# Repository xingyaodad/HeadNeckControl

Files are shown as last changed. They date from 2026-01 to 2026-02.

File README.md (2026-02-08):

# 🤖 HeadNeckControl

<div align="center">

## 🎯 基于RBF的仿生颈部舵机控制系统

### 🦾 通过肌腱实现仿生头部的实时控制和动画播放

</div>

---

## 📹 效果展示

### 👻 仿生脖子运行演示

<div align="center">

 <!-- 替换为你的实际 GIF 文件 -->
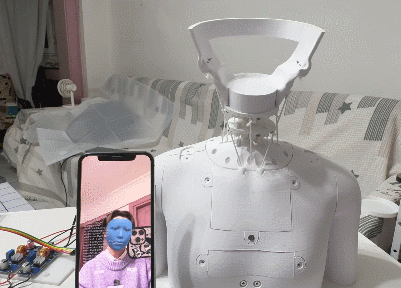
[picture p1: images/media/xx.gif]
仿生脖子运行演示


✨ *仿生脖子实时追踪演示* ✨

</div>

---

## 📖 项目简介

HeadNeckControl 是一个完整的仿生颈部控制系统，通过树莓派和 PCA9685 驱动舵机拉动肌腱来模拟肌肉的方式控制仿生头部的运动。系统支持多种控制方式：手机 ARKit 面部追踪、动画文件播放、Windows 端手动控制和测试模式，可以精确控制头部的俯仰、偏航和滚动三个自由度。

## ✨ 功能特点

- 📱 **ARKit 实时追踪**：通过 iOS 设备使用 ARKit 捕捉面部姿态，通过 UDP 直接发送到树莓派进行实时控制
- 🎮 **Unity iOS 应用**：提供完整的 Unity 项目，用于生成 ARKit 面部追踪 iOS 应用，支持自定义和扩展
- 🎬 **动画播放**：支持播放预设的头部动作序列，动画文件存储在树莓派本地
- 🖱️ **Windows 手动控制**：提供图形界面，可通过滑块直接控制舵机角度
- 🔧 **测试模式**：用于调试和校准舵机的测试模式
- 🎨 **平滑过渡**：使用 RBF（径向基函数）插值算法，实现流畅的动作过渡
- 🔄 **多输入源**：支持多种输入源的灵活切换

## 🏗️ 系统架构

```
┌─────────────────┐     UDP      ┌──────────────────┐
│  Windows App    │ ───────────> │  Raspberry Pi    │
│  (C# .NET 8)    │              │   (Python 3.11)  │
│                 │              │                  │
│  - TrackBar     │              │  - BaseInput     │
│  - 手动控制      │              │  - HeadMapper    │
└─────────────────┘              │ - ServoController│
                                 └────────┬─────────┘
                                          │
                            UDP           │ I2C
┌─────────────────┐                       │
│   iOS Device    │ ──────────────────────┤
│   (ARKit)       │                       ▼
└─────────────────┘              ┌──────────────┐
                                 │   PCA9685    │
                                 │ (PWM Driver) │
                                 └──────┬───────┘
                                        │
                                       舵机
                                        ▼
                                 ┌──────────────┐
                                 │  仿生头部     │
                                 └──────────────┘
```

**📡 数据流向说明**：
- 💻 **Windows 端**：通过滑块手动控制舵机角度，通过 UDP 发送舵机角度数据到树莓派
- 🍎 **iOS ARKit 端**：直接通过 UDP 发送 ARKit 捕捉的面部姿态数据到树莓派
- 🎞️ **动画播放**：动画文件（`.anim`）存储在树莓派本地，由树莓派读取并播放
- 🥧 **树莓派**：作为控制中心，接收所有输入源数据，经过 HeadMapper 映射后控制舵机

## 🛒 硬件清单

### 📦 必备硬件

- 🥧 **树莓派**：3B+ 或更高版本
- 💻 **windows电脑**：随意，与树莓派需连统一局域网
- 🔌 **PCA9685 PWM 驱动板**：一块
- ⚙️ **舵机**：MG996R 或类似的金属齿轮舵机 （8个），每个需要十字舵臂，提前设置到90度
- 🔋 **电源**：12V 100W电源 + 2-4个5V5A降压模块（可根据实际情况调整）
- 🔗 **杜邦线、导线**：若干，连接电源、树莓派、PCA9685 和舵机
- 🧵 **dyneema绳**：直径1.5mm 5米，使用前需要做预拉伸（找个重物吊个一两天）裁成12条35cm长的线段
- 🔬 **特氟龙硬管**：内径2mm * 外径3mm 2米，根据image文件夹里的图片截成相应长度的段
- 💎 **陶瓷眼**：小外径3.9 * 孔2.3 * 总高6 （25个）
- ⭕ **小轴承**：9 * 14 * 2.5 （8个）
- 🫧 **TPU胶圈**：直径8mm * 宽2mm （8个），可以用差不多的橡皮筋
- 💧 **胶水**：502或其他快干胶
- 🔩 **螺丝**：平头自攻M3 * 8 （50个），平头M3 * 5 (8个),平头自攻M2 * 10 （32个），平头自攻M2 * 8 （12个），M2 * 10 + 螺母 （8组）（螺丝建议多备些，很容易丢😅）

### 🛠️ 可选硬件

- 🧩 **面包板（可选）**：用于电路连接
- 🧴 **锁边液（可选）**：用于把毛躁的线头弄顺，可以更好的穿孔，也可以用普通的办公胶水代替
- 🪄 **润滑脂（可选）**：关节交接处的润滑，最好有

### 🔧 希望你可以有的一些工具

- ✂️ **螺丝刀、钳子**：如果没有的话就放弃这个项目吧👋
- 🖨️ **FDM 3D打印机**：最大打印尺寸最好超过200 * 200 * 200，没有的话找个代打吧~
- 💪 **电磨**：用于清理打磨模型粗糙的细节，实在没有用砂纸也不是不行

### 🌟 最后希望你可以有

- 🏆 **很强的动手能力**：这个项目所有东西都需要你自己亲自组装😅
- 💖 **很强的耐心**：这套脖子比例大小是按照真实5-6岁孩子尺寸设计的，很多部件非常小且难安装，所以如果你已经开始了，那么一定要耐心一点❤

## 🚀 快速开始

### 🧩 模型组装以及控制
- **请移步B站观看视频**：[闺女脖子开源啦！！](https://www.bilibili.com/video/BV1u9FxzGEDt)

### 🥧 树莓派环境配置

#### 1️⃣ 系统要求
- **操作系统**：Raspberry Pi OS
- **Python 版本**：Python 3.10 或更高（本系统使用 Python 3.11）
- **内存**：至少 2GB RAM（推荐 4GB）

#### 2️⃣ 克隆项目（建议在pc上克隆好，不要在树莓派上克隆，把RaspberryPi文件夹拷贝到树莓派上）

```bash
cd ~
git clone https://github.com/yourusername/HeadNeckControl.git
cd HeadNeckControl/RaspberryPi
```

#### 3️⃣ 安装 Python 依赖

```bash
# 更新系统
sudo apt update
sudo apt upgrade -y

# 安装系统依赖
sudo apt install -y python3-pip python3-dev

# 安装 Python 包
pip3 install -r requirements.txt
```

#### 4️⃣ 启用 I2C 接口

```bash
# 方法 1：使用 raspi-config
sudo raspi-config
# 选择 Interface Options -> I2C -> Enable

# 方法 2：命令行
sudo apt install -y i2c-tools
sudo raspi-config nonint do_i2c 0

# 重启树莓派
sudo reboot
```

#### 5️⃣ 验证 I2C 连接

重启后，检查 PCA9685 是否被识别：🔍

```bash
# 列出所有 I2C 设备
i2cdetect -y 1

# 应该看到类似输出（0x40 是 PCA9685 默认地址）：
#      0  1  2  3  4  5  6  7  8  9  a  b  c  d  e  f
# 00:          -- -- -- -- -- -- -- -- -- -- -- -- --
# 10: -- -- -- -- -- -- -- -- -- -- -- -- -- -- -- --
# 20: -- -- -- -- -- -- -- -- -- -- -- -- -- -- -- --
# 30: -- -- -- -- -- -- -- -- -- -- -- -- -- -- -- --
# 40: 40 -- -- -- -- -- -- -- -- -- -- -- -- -- --
# ...
```

如果看到 `40`，说明 PCA9685 已正确连接。

#### 6️⃣ 配置 config.py

编辑 `RaspberryPi/config.py` 文件，根据你的硬件和网络环境修改以下配置：

```python
class Config():
    DEBUG = True              # 调试模式：True=不操作硬件，仅打印数值；False=实际控制舵机
    ip = ''                   # 树莓派 IP 地址（留空自动检测，或手动填写如 '192.168.1.100'）
    port = 9003               # UDP 监听端口（接收 ARKit/Windows 数据）
    servo_count = 8           # 所有舵机数量
    test_servo_count = 8      # 测试模式下舵机数量
    pca9685_address = [0x40]  # PCA9685 驱动板 I2C 地址（可支持多个板）
    pca_frequency = 50        # PWM 频率（Hz），舵机通常为 50
    is_anim = False           # 是否加载动画文件，不用改，根据选项会自动改
    anim_file = 'anim_data/neck.anim'           # 动画文件路径
    neck_config_file = 'controller/neck_matrix_config.json'  # 舵机角度映射配置文件，从widows输出的矩阵文件
```

**⚙️ 配置说明**：
- **首次运行**建议保持 `DEBUG = True`，验证数据接收和映射逻辑正常后再改为 `False`
- `ip` 留空时会自动检测树莓派的 IP 地址；如果网络环境复杂，可手动指定
- `port` 需要与 Windows 端和 iOS 端的发送端口一致
- 如需添加更多 PCA9685 板，在 `pca9685_address` 列表中添加地址（如 `[0x40, 0x41]`）
- `neck_config_file` 中的配置由 Windows 端的工具生成

## 📁 项目结构

```
HeadNeckControl/
 ├── RaspberryPi/              # 树莓派端代码（Python）
 │   ├── main.py             # 主程序入口
 │   ├── config.py           # 配置文件
 │   ├── controller/         # 控制器模块
 │   │   ├── servo_controller.py   # 舵机控制器
 │   │   └── head_mapper.py       # 头部姿态映射器
 │   ├── input/              # 输入源模块
 │   │   ├── base_input.py        # 输入源基类
 │   │   ├── input_arkit.py       # ARKit 输入源
 │   │   ├── input_anim.py        # 动画文件输入源
 │   │   ├── input_ai.py          # AI 输入源
 │   │   └── input_test.py       # 测试输入源
 │   ├── utils/              # 工具模块
 │   │   └── filetools.py        # 文件处理工具
 │   ├── anim_data/          # 动画文件目录
 │   └── requirements.txt    # Python 依赖
 │
 ├── Windows/                # Windows 端代码（C#）
 │   └── NeckControlOutput/
 │       ├── Form1.cs            # 主窗体
 │       ├── Form1.Designer.cs   # 窗体设计器（自动生成）
 │       ├── Models.cs           # 数据模型
 │       ├── RBFHelper.cs        # RBF 插值助手
 │       ├── WeightMatrixHelper.cs # 权重矩阵计算
 │       ├── Program.cs          # 程序入口
 │       └── NeckControlOutput.csproj # 项目文件
 │
 ├── UnityArkit/              # Unity iOS ARKit 应用
 │   ├── Assets/             # Unity 资源和脚本
 │   │   ├── Scenes/          # 场景文件
 │   │   ├── Scripts/         # C# 脚本
 │   │   └── Samples/         # AR Foundation 示例
 │   ├── Packages/           # Unity 包配置
 │   ├── ProjectSettings/     # 项目设置
 │   └── UnityArkit.sln     # 解决方案文件
 │
 ├── 3D-Models/              # 3D 打印模型文件
 │   ├── OBJ/                 # Wavefront OBJ 格式模型
 │   ├── 3MF/                 # Bambu Studio 切片格式模型
 │   └── README.md            # 3D 打印说明
 │
 ├── AGENTS.md               # 开发者指南
 ├── CHECKLIST.md            # 项目检查清单
 ├── CONTRIBUTING.md         # 贡献指南
 ├── LICENSE                # MIT 许可证
 ├── PACKAGING.md            # 打包发布指南
 ├── README.md              # 本文件
 └── .gitignore            # Git 忽略规则
 ```

## 🤝 贡献

欢迎贡献代码、报告问题或提出改进建议！请阅读 [CONTRIBUTING.md](CONTRIBUTING.md) 了解详情。

## 📜 许可证

本项目采用 MIT 许可证 - 详见 [LICENSE](LICENSE) 文件。

## 🙏 致谢

- Adafruit 的 [CircuitPython](https://circuitpython.org/) 库

## 📺 欢迎围观我的B站

- 📺 B站 [星瑶爸爸呀](https://space.bilibili.com/26313918)

---

<div align="center">

**Made with ❤️ by 🌟 Robotics Enthusiasts** 🤖✨

</div>

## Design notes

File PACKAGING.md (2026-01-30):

# 打包发布指南

本文档说明如何打包和发布 HeadNeckControl 项目。

## Windows 端打包

### 1. 编译 Release 版本

```bash
cd Windows/NeckControlOutput
dotnet build --configuration Release
```

编译后的文件位于：`bin/Release/net8.0-windows/`

### 2. 复制配置文件

Release 编译不会自动包含配置文件，需要手动复制：

```bash
cp neck_config.example.json bin/Release/net8.0-windows/neck_config.json
```

### 3. 打包为 ZIP

将以下文件打包为 ZIP：
- `NeckControlOutput.exe`
- `NeckControlOutput.dll`
- `NeckControlOutput.deps.json`
- `NeckControlOutput.runtimeconfig.json`
- `NumSharp.dll`
- `Numpy.dll`
- `Python.Runtime.dll`
- `Python.Included.dll`
- `Python.Deployment.dll`
- `neck_config.json`

```bash
cd bin/Release/net8.0-windows
zip -r HeadNeckControl-Windows.zip *.dll *.json *.exe
```

### 4. 用户使用

用户下载 ZIP 后：
1. 解压到任意目录
2. 双击 `NeckControlOutput.exe` 运行
3. 首次运行会自动加载或创建配置文件

## 树莓派端打包

### 1. 确保配置文件完整

```bash
cd RaspberryPi
ls -la controller/neck_matrix_config.json
```

### 2. 打包为 ZIP

```bash
cd RaspberryPi
zip -r HeadNeckControl-RaspberryPi.zip \
  *.py \
  config.py \
  controller/ \
  input/ \
  utils/ \
  requirements.txt
```

### 3. 用户部署

用户下载 ZIP 后：
```bash
# 解压
unzip HeadNeckControl-RaspberryPi.zip -d ~/HeadNeckControl
cd ~/HeadNeckControl

# 安装依赖
pip3 install -r requirements.txt

# 运行
python3 main.py
```

## GitHub Release

### 1. 创建 Tag

```bash
git tag -a v1.0.0 -m "Release v1.0.0"
git push origin v1.0.0
```

### 2. 创建 Release

在 GitHub 上：
1. 进入 "Releases" 页面
2. 点击 "Draft a new release"
3. 选择 Tag: v1.0.0
4. 填写 Release Notes
5. 上传打包的 ZIP 文件：
   - `HeadNeckControl-Windows.zip`
   - `HeadNeckControl-RaspberryPi.zip`
6. 点击 "Publish release"

### 3. Release Notes 模板

```markdown
## HeadNeckControl v1.0.0

### 下载

- [Windows 版本](HeadNeckControl-Windows.zip) - 适用于 Windows 10/11
- [树莓派版本](HeadNeckControl-RaspberryPi.zip) - 适用于 Raspberry Pi OS

### 新功能
- 支持 ARKit 实时面部追踪
- 支持动画文件播放
- Windows 端图形界面手动控制
- RBF 插值平滑过渡

### 系统要求

**Windows**：
- Windows 10/11
- .NET 8.0 Runtime（包含在 ZIP 中）

**树莓派**：
- Raspberry Pi 3B+ 或更高
- Raspberry Pi OS Bullseye/Bookworm
- Python 3.10+

### 快速开始

详细说明请参考 [README.md](../../README.md)

### 已知问题
- 无

### 更新日志
- 初始版本发布
```

## 注意事项

1. **配置文件**：确保示例配置文件包含在发行版中
2. **依赖库**：Windows 端需要将 NuGet 包的 DLL 包含在 ZIP 中
3. **版本号**：更新 NeckControlOutput.csproj 中的版本号
4. **文档**：确保 README 和 AGENTS.md 已更新
5. **测试**：在发布前在干净环境中测试 ZIP 文件

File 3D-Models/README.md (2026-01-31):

# 3D 打印模型文件

本目录包含 HeadNeckControl 仿生颈部控制系统的 3D 打印模型文件。

## 目录结构

```
3D-Models/
├── OBJ/          # Wavefront OBJ 格式模型
├── 3MF/          # Bambu Studio 切片格式文件
└── README.md      # 本文件
```

## 打印建议

### 所有主体
- **材料**：PLA 或 PETG（推荐 PETG）
- **打印参数**：参考3mf文件里的配置

### 颈部连接件
- **材料**：PA（尼龙）
- **打印参数**：参考3mf文件里的配置
- **打磨**：拆完支撑后最好把接触面打磨一下

## 注意事项

**因为制作模型单位问题，如果自己把模型导入切片软件需要放大十倍！！！放大十倍！！！**

## 许可证

3D 模型文件遵循项目的 MIT 许可证。

<div align="center">

**Happy 3D Printing! 🖨️**

</div>

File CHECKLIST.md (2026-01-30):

# 项目检查清单

## 下载后可运行性检查

### 树莓派端

- [x] **.gitignore 配置正确**
  - ✅ `RaspberryPi/controller/neck_matrix_config.json` 已被包含（不会忽略）
  - ✅ 示例文件 `neck_matrix_config.example.json` 已创建
  - ✅ 用户可运行的配置文件存在

- [x] **必需文件已提交**
  - ✅ 所有 Python 源码文件
  - ✅ `requirements.txt` 包含所有依赖
  - ✅ `config.py` 配置文件
  - ✅ `neck_matrix_config.json` 默认配置

- [x] **用户使用流程**
  ```bash
  # 1. 克隆项目
  git clone https://github.com/yourusername/HeadNeckControl.git
  cd HeadNeckControl/RaspberryPi

  # 2. 安装依赖
  pip3 install -r requirements.txt

  # 3. 运行程序
  python3 main.py
  ```

### Windows 端

- [x] **.gitignore 配置正确**
  - ✅ 编译产物（bin/、obj/）已忽略
  - ✅ 用户配置文件 `Windows/NeckControlOutput/*/neck_config.json` 已忽略
  - ✅ 示例文件 `neck_config.example.json` 已创建

- [x] **必需文件已提交**
  - ✅ 所有 C# 源码文件
  - ✅ `NeckControlOutput.csproj` 项目文件
  - ✅ `neck_config.example.json` 示例配置

- [x] **用户使用流程**
  ```bash
  # 1. 克隆项目
  git clone https://github.com/yourusername/HeadNeckControl.git
  cd HeadNeckControl/Windows

  # 2. 编译项目
  dotnet build

  # 3. 运行程序
  cd NeckControlOutput/bin/Debug/net8.0-windows
  ./NeckControlOutput.exe
  ```

## EXE 生成检查

### Debug 模式
- [x] `dotnet build` 成功
- [x] 生成 `NeckControlOutput.exe` 在 `bin/Debug/net8.0-windows/`
- [x] 所有依赖 DLL 已生成
- [x] `neck_config.json` 自动生成或可从示例复制

### Release 模式
- [x] `dotnet build --configuration Release` 成功
- [x] 生成 `NeckControlOutput.exe` 在 `bin/Release/net8.0-windows/`
- [x] 所有依赖 DLL 已生成
- [x] 可打包为独立 ZIP 分发

## 配置文件检查

### 树莓派端
- [x] `neck_matrix_config.json` 存在且格式正确
- [x] `neck_matrix_config.example.json` 作为参考
- [x] 包含 RBF 矩阵和舵机范围配置

### Windows 端
- [x] `neck_config.example.json` 存在且格式正确
- [x] 运行时自动创建 `neck_config.json`
- [x] 包含 IP、端口、舵机标签配置

## 文档完整性

- [x] **README.md**
  - ✅ 项目简介和功能特点
  - ✅ 系统架构图
  - ✅ 硬件清单
  - ✅ 详细的安装步骤（删除了虚拟环境）
  - ✅ 配置文件说明
  - ✅ 常见问题 FAQ
  - ✅ 调试技巧

- [x] **AGENTS.md**
  - ✅ 构建和测试命令
  - ✅ 代码风格指南（Python 和 C#）
  - ✅ 架构设计模式
  - ✅ 常见问题
  - ✅ 纯中文

- [x] **CONTRIBUTING.md**
  - ✅ 贡献指南
  - ✅ Issue 和 PR 流程
  - ✅ 纯中文

- [x] **PACKAGING.md**（新增）
  - ✅ Windows 端打包指南
  - ✅ 树莓派端打包指南
  - ✅ GitHub Release 流程
  - ✅ Release Notes 模板

- [x] **.github/PULL_REQUEST_TEMPLATE.md**
  - ✅ PR 模板

- [x] **LICENSE**
  - ✅ MIT 许可证

## 网络配置检查

- [x] **树莓派**
  - ✅ UDP 端口 9003
  - ✅ IP 地址自动获取或手动配置

- [x] **Windows**
  - ✅ UDP 发送端口 5001
  - ✅ 默认目标地址 192.168.3.11:9003

## 已知问题

### 当前存在的问题
⚠️ `head_mapper.py` 第 21 行没有错误处理
   - 如果配置文件缺失会直接崩溃
   - 建议：添加 try-except 处理文件不存在的情况

### .gitignore 配置说明
✅ 已修复以下问题：
1. 之前：`*config.json` 会忽略所有配置文件
2. 现在：明确指定要保留的配置文件路径

### Windows 端配置文件
✅ 已处理：
1. 示例文件 `neck_config.example.json` 已创建
2. 用户运行时会自动创建 `neck_config.json`
3. Release 打包时需要手动复制配置文件

## 下一步建议

1. **改进错误处理**
   - 在 `head_mapper.py` 中添加配置文件缺失的处理
   - 在 Windows 端添加配置文件损坏的处理

2. **添加安装脚本**
   - 树莓派端：`install.sh` 自动安装依赖和配置
   - Windows 端：安装程序或批处理脚本

3. **添加单元测试**
   - Python 端：pytest 测试
   - Windows 端：xUnit 测试

4. **文档国际化**
   - 考虑添加英文版本 README（根据需要）

## 总结

✅ **项目已完全准备好开源**

用户下载后可以：
1. **树莓派端**：直接运行 `python3 main.py`
2. **Windows 端**：编译后运行 `dotnet run` 或生成的 exe
3. **配置文件**：有默认配置，可直接使用

所有必要的文件都已包含，.gitignore 配置正确，文档完整。

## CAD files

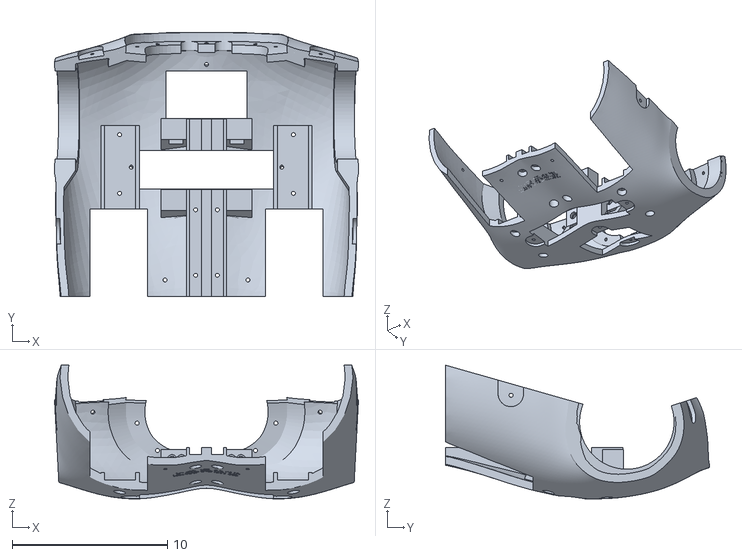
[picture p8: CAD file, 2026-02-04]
3D-Models/body2.obj
19.6 x 17.0 x 8.63

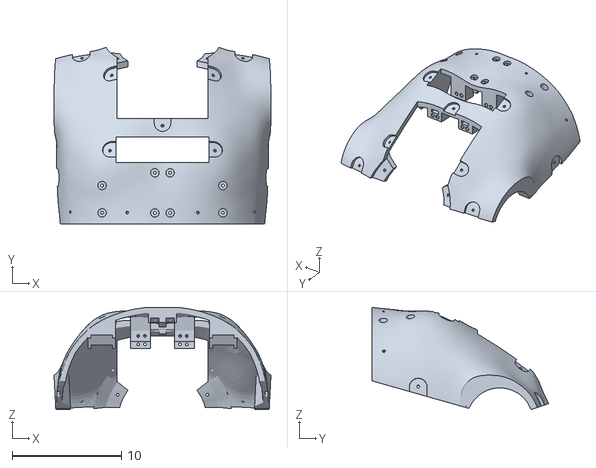
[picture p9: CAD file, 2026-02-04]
3D-Models/body1.obj
19.9 x 16.2 x 9.38

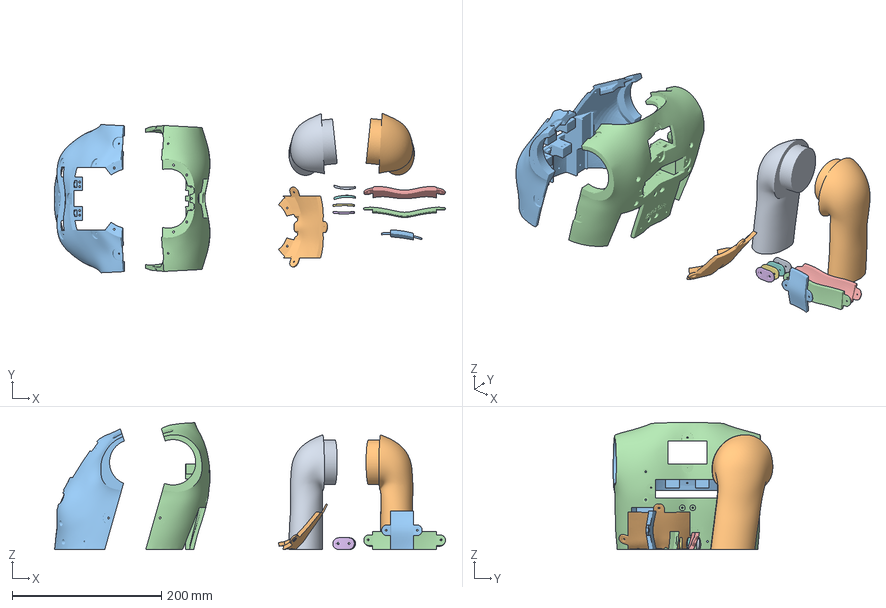
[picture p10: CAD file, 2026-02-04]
3D-Models/身体.3mf
524.8 x 214.3 x 170.5 mm
arm_right.obj x 2
back_block1.obj
back_block2.obj
chest_block2.obj
fixed_block_left.obj
fixed_block_right.obj
upper_fixed_block_left.obj
upper_fixed_block_right.obj
chest_block1.obj
body1.obj
body2.obj

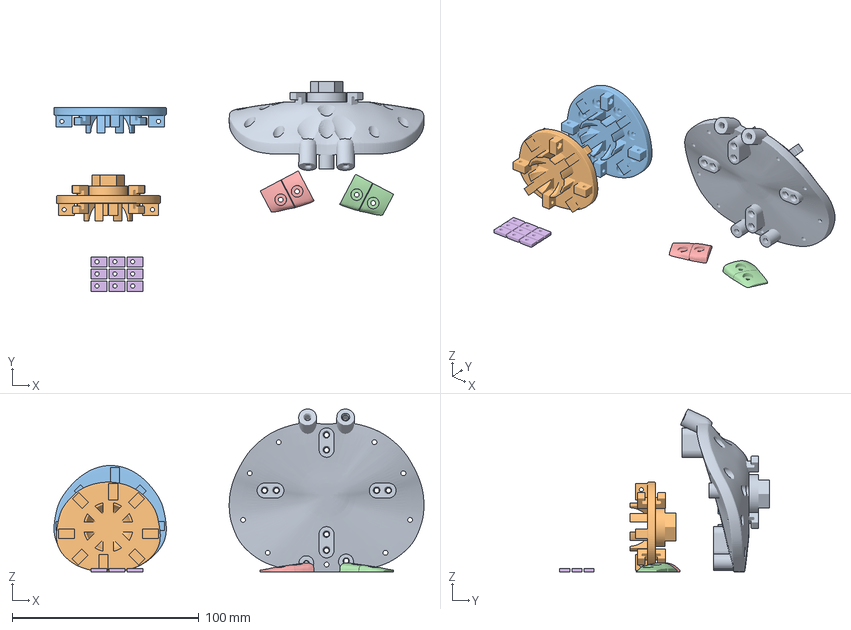
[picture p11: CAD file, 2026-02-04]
3D-Models/脖子结构.3mf
198.4 x 112.4 x 87.4 mm
neck1.obj
neck2.obj
neck3.obj
head_cable_clamp_left.obj
head_cable_clamp_right.obj
组合体

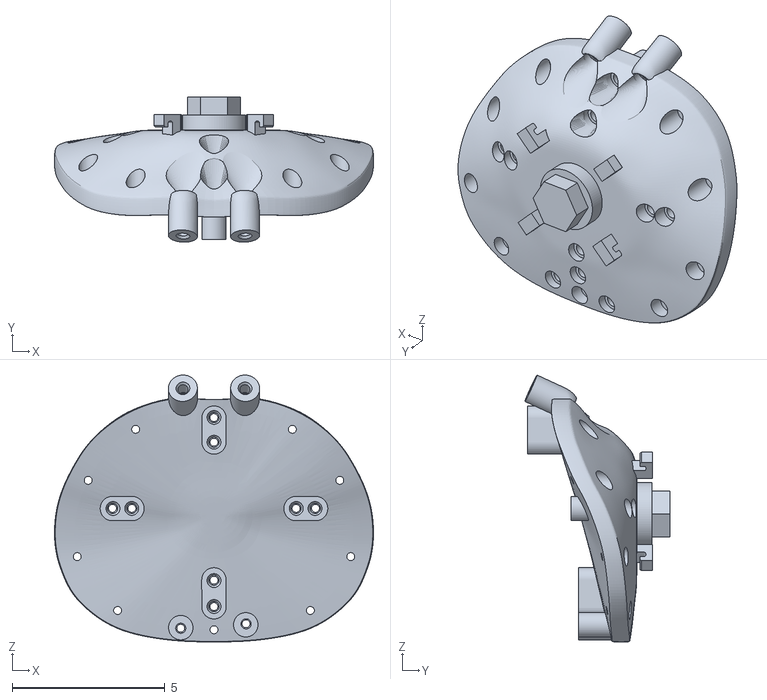
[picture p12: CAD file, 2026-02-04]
3D-Models/neck1.obj
10.4 x 4.76 x 8.74

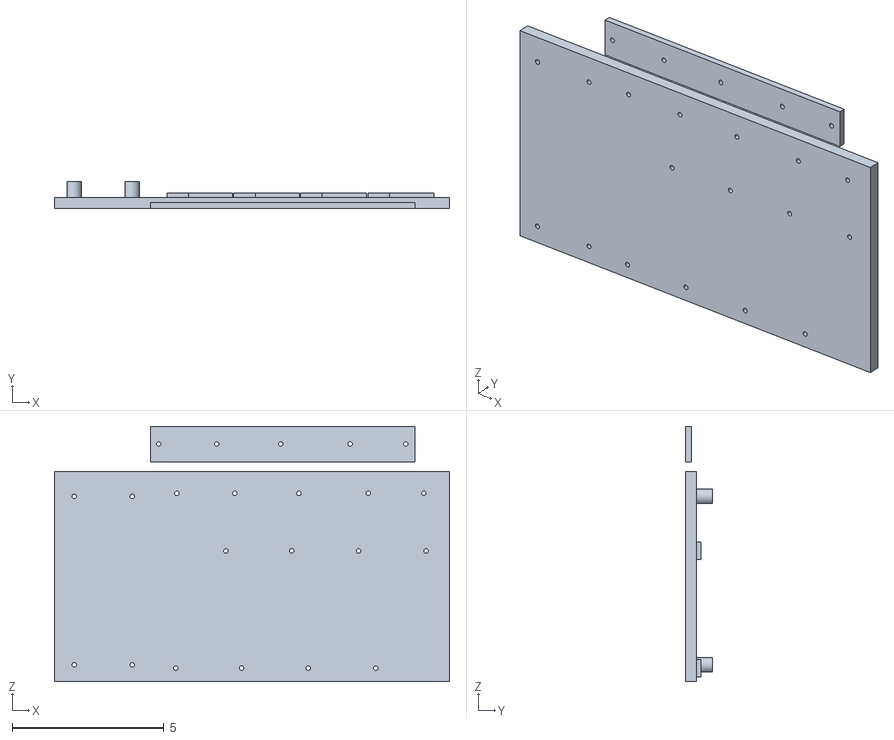
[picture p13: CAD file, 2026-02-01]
3D-Models/other.obj
13.0 x 0.881 x 8.41

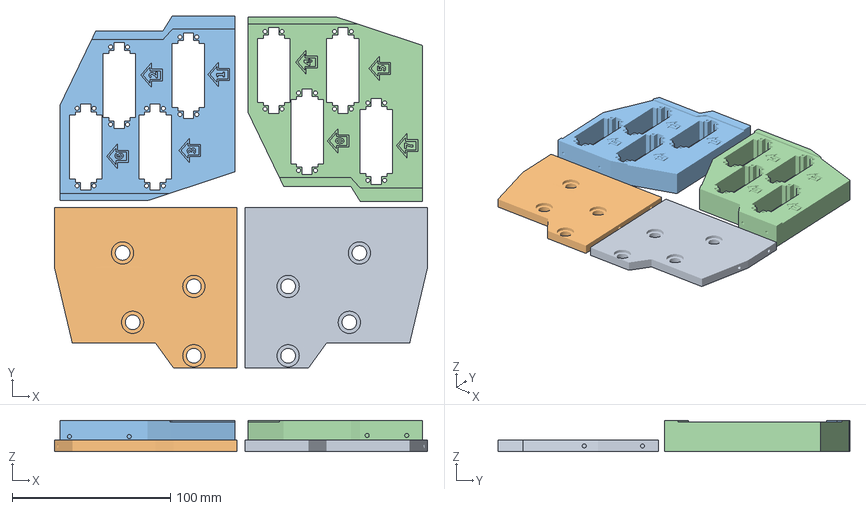
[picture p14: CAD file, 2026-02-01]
3D-Models/舵机仓.3mf
235.6 x 222.3 x 19.9 mm
insert_panel_left.obj
insert_panel_right.obj
servo_compartment_left.obj
servo_compartment_right.obj

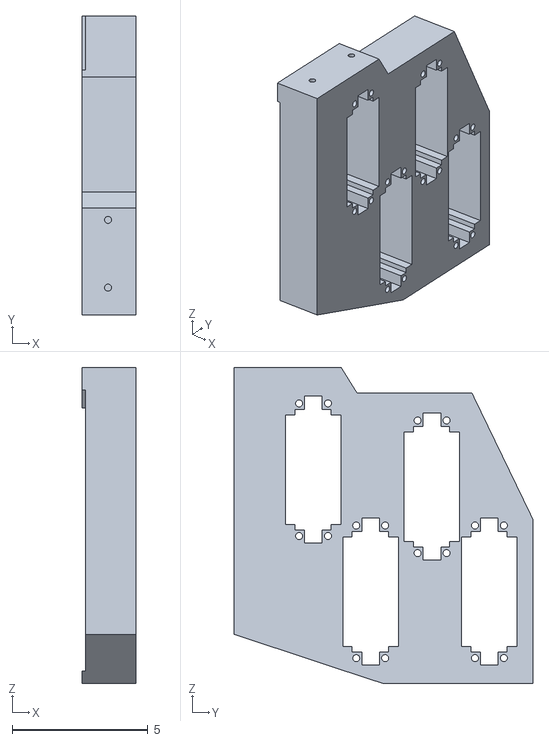
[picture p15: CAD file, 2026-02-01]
3D-Models/servo_compartment_left.obj
1.99 x 11.0 x 11.7

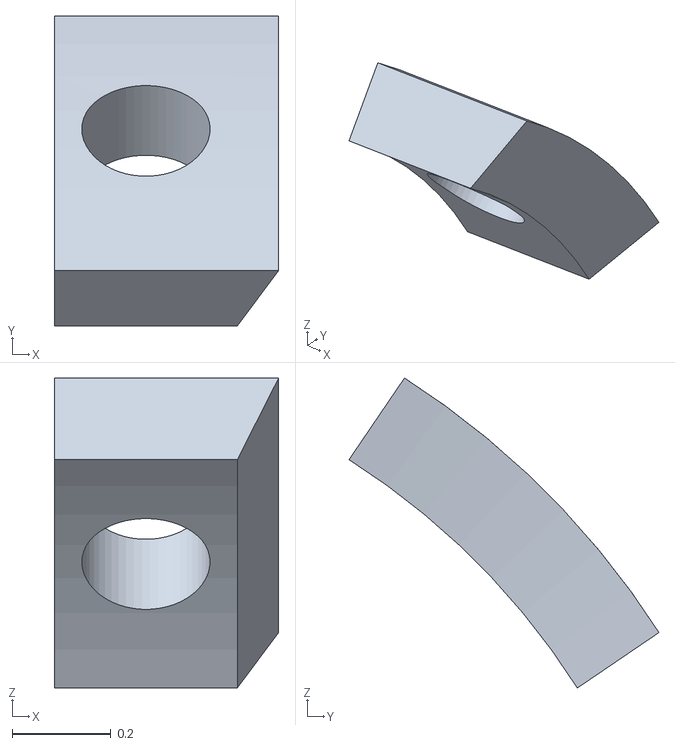
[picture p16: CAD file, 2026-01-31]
3D-Models/guide_cable_clamp1_x8.obj
0.455 x 0.628 x 0.628

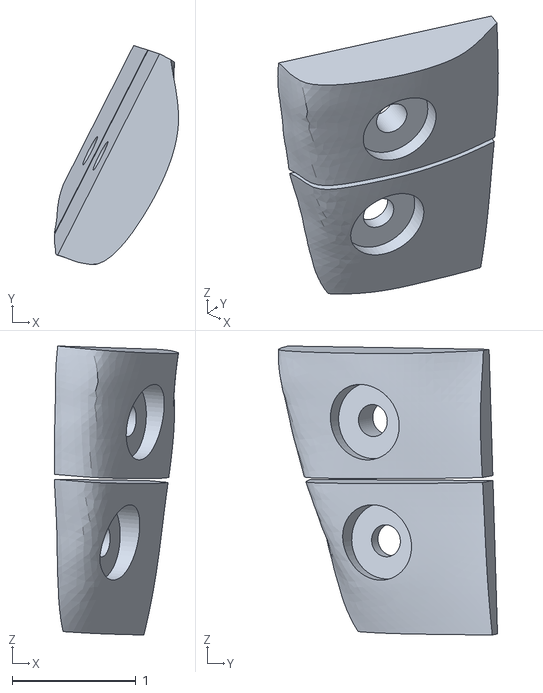
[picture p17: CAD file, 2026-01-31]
3D-Models/head_cable_clamp_left.obj
1.00 x 1.77 x 2.34

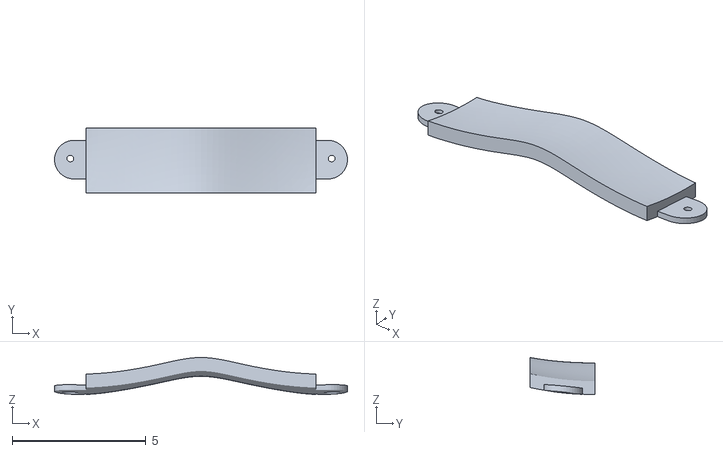
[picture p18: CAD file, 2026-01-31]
3D-Models/back_block2.obj
11.0 x 2.44 x 1.39

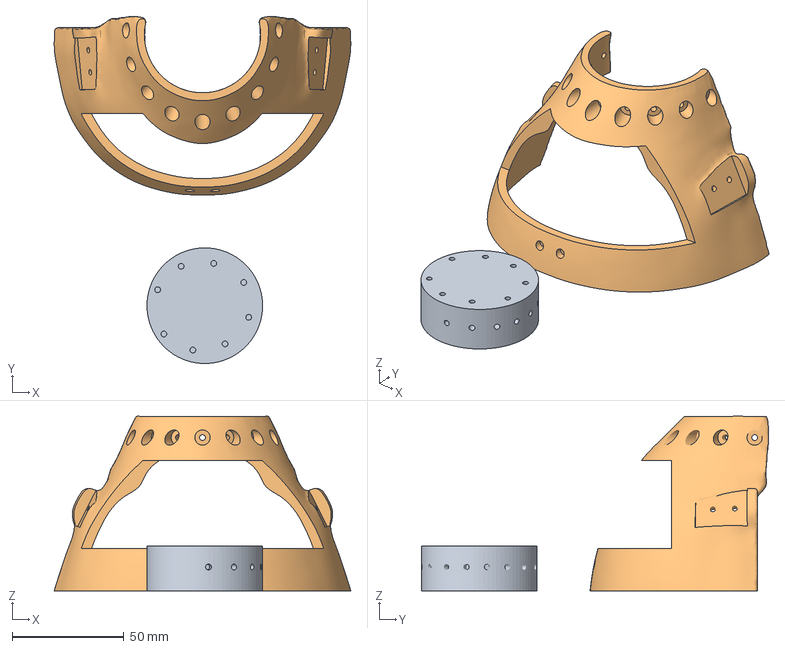
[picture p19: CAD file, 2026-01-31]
3D-Models/半个头骨.3mf
132.8 x 155.4 x 78.2 mm
platform.obj
half_skull.obj

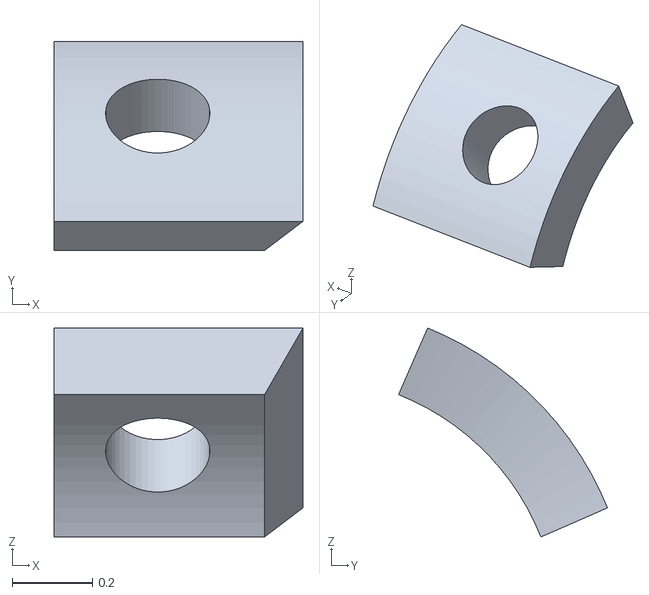
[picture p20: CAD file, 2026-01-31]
3D-Models/guide_cable_clamp2_x4.obj
0.62 x 0.521 x 0.52

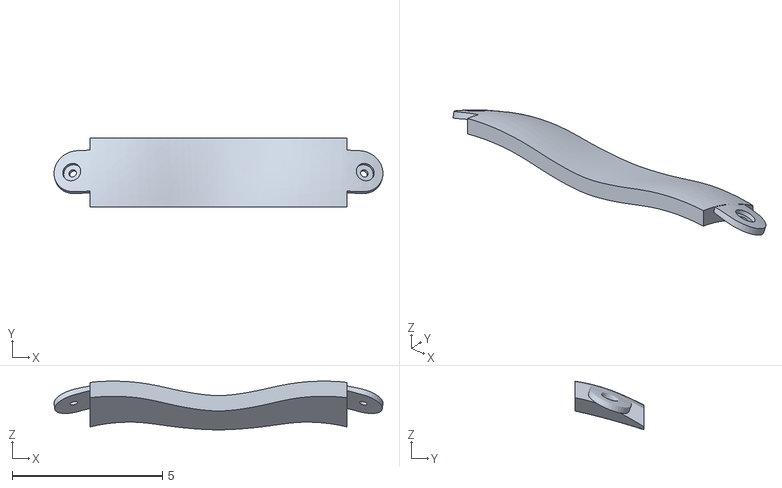
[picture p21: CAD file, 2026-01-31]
3D-Models/chest_block2.obj
10.9 x 2.30 x 1.62

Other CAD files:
3D-Models/servo_compartment_right.obj
3D-Models/head_cable_clamp_right.obj
3D-Models/拉线机构.3mf
3D-Models/neck_support3.obj
3D-Models/back_block1.obj
3D-Models/cable_clamp_x8.obj
3D-Models/cable_guide.obj
3D-Models/chest_block1.obj
3D-Models/fixed_block_left.obj
3D-Models/fixed_block_right.obj
3D-Models/insert_panel_left.obj
3D-Models/insert_panel_right.obj
3D-Models/neck2.obj
3D-Models/neck3.obj
3D-Models/neck_support1.obj
3D-Models/neck_support2.obj
3D-Models/neck_support4.obj
3D-Models/platform.obj
3D-Models/upper_fixed_block_left.obj
3D-Models/upper_fixed_block_right.obj
3D-Models/脖子中间支撑_PA.3mf

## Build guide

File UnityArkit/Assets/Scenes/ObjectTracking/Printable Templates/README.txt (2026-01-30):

You may print these templates to create the 3D objects that are included in the reference object library in this sample.

The CubeTemplatePNG is meant to be cut out and folded to create a paper cube.

The CanWrapUnity is meant to be printed out and wrapped around a soda can, water bottle, or similar object.

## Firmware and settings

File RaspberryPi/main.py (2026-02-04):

from config import Config
from input.input_anim import AnimInput
from input.input_arkit import ArkitInput
from input.input_test import Test
from controller.servo_controller import ServoController
from controller.head_mapper import HeadMapper
import time

if not Config.DEBUG:
    import board
    import busio
import sys

# 初始化 I2C 连接
i2c = None
if not Config.DEBUG:
    i2c = busio.I2C(board.SCL, board.SDA)

servo_ctrl = ServoController(
    i2c=i2c, address=Config.pca9685_address, servo_count=Config.servo_count
)
servo_ctrl.start()

run_thread = None
head_mapper = None


def run_anim():
    global run_thread, head_mapper
    Config.is_anim = True
    try:
        head_mapper = HeadMapper(Config.neck_config_file)
    except ValueError as e:
        print(f"错误: {e}")
        print("请检查配置文件格式，或使用 Windows 端重新生成配置文件。")
        return
    except Exception as e:
        print(f"加载配置文件时发生未知错误: {e}")
        return
    run_thread = AnimInput(Config.anim_file, controller=servo_ctrl, mapper=head_mapper)
    run_thread.start()


def run_arkit():
    global run_thread, head_mapper
    Config.is_anim = False
    try:
        head_mapper = HeadMapper(Config.neck_config_file)
    except ValueError as e:
        print(f"错误: {e}")
        print("请检查配置文件格式，或使用 Windows 端重新生成配置文件。")
        return
    except Exception as e:
        print(f"加载配置文件时发生未知错误: {e}")
        return
    run_thread = ArkitInput(
        Config.ip, Config.port, controller=servo_ctrl, mapper=head_mapper
    )
    run_thread.start()


def test():
    global run_thread
    Config.is_anim = True
    run_thread = Test(
        Config.ip, Config.port, servo_ctrl, servo_count=Config.test_servo_count
    )
    run_thread.start()


def exit_out():
    if run_thread != None:
        run_thread.stop()
    servo_ctrl.stop()
    exit()


modes = {
    1: ("ARKit 实时捕捉", run_arkit),
    2: ("播放动画文件", run_anim),
    3: ("测试", test),
    4: ("退出", exit_out),
}

if __name__ == "__main__":
    print("请选择启动模式：")
    for num, (desc, _) in modes.items():
        print(f"{num}. {desc}")
    try:
        while True:
            choice = int(input("输入数字").strip())
            if choice in modes:
                print(f"\n 启动：{modes[choice][0]}\n")
                modes[choice][1]()  # 调用对应的函数

    except ValueError:
        print("请输入合法数字")

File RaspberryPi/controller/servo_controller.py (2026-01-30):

from config import Config
import time
import threading
import queue
from adafruit_motor import servo
from adafruit_pca9685 import PCA9685

class ServoController():
    def __init__(self,i2c,address=[0x40],pca_frequency = 50,servo_count = 16):
        self.pca = []
        if not Config.DEBUG:
            for addres in address:
                pca = PCA9685(i2c,address=addres)
                pca.frequency = pca_frequency
                self.pca.append(pca)
        self.servo_count = servo_count
        self.all_servo = []
        tem_count = 0
        if not Config.DEBUG:
            for i in range(len(address)):
                for j in range(16):
                    self.all_servo.append(servo.Servo(self.pca[i].channels[j], min_pulse = 500, max_pulse = 2500))
                    tem_count += 1
                    if tem_count >= servo_count:
                        break
        self.last_angles = [0] * servo_count
        self.queue = queue.Queue()
        self.running = False
        self.thread = None
        
    def _executor_loop(self):
        while self.running:
            try:
                item = self.queue.get(timeout=0.1)
                
                if isinstance(item, dict):
                    for i, angle in item.items():
                        self.set_angle(i, angle)
                elif isinstance(item, list) and all(isinstance(a, (int, float)) for a in item):
                    self.set_angles(item)
                elif isinstance(item, list) and all(isinstance(a, (tuple, list)) for a in item):
                    for i, angle in item:
                        self.set_angle(i, angle)
                else:
                    print(f" 无效舵机任务格式：{item}")
            except queue.Empty:
                continue
    def put(self, task):
        """
        task 可以是：
        - dict: {通道:角度}
        - list of float: 所有通道角度列表
        - list of (通道, 角度) 对
        """
        self.queue.put(task)

    def start(self):
        self.running = True
        self.thread = threading.Thread(target=self._executor_loop, daemon=True)
        self.thread.start()

    def stop(self):
        self.running = False
        if self.thread and self.thread.is_alive():
            self.thread.join()

    def set_angle(self, channel_index, angle):
        """
        直接设置单个舵机角度（立即生效）
        """
        if channel_index >= self.servo_count:
            print(f" 通道 {channel_index} 不对")
            return
        if Config.DEBUG:
            print([channel_index,angle])
        else:
            self.all_servo[channel_index].angle = angle  
    
    def set_angles(self,angles):
        if Config.DEBUG:
            print(angles)
            return
        for i in range(len(angles)):
            if self.last_angles[i] != angles[i]:
                self.all_servo[i].angle = angles[i]
                self.last_angles[i] = angles[i]

    def get_servo_count(self):
        return len(self.all_servo)

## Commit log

2026-01-30 第一次上传文件
2026-01-30 增加3d模型的文件目录
2026-01-30 添加角度限制
2026-01-30 添加unity ios手机应用工程，用来实时获取发送脖子数据
2026-01-31 添加所有3d打印需要的模型
    [back_block1.obj, back_block2.obj, cable_clamp_x8.obj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]
2026-01-31 增加创建动画专用文件
2026-02-03 更新一些模型细节
    [body2.obj, neck1.obj, 脖子结构.3mf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]
2026-02-03 更新动画文件
2026-02-04 更新模型一些细节
    [body1.obj, body2.obj, neck1.obj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]
2026-02-04 修改测试模式下不加载HeadMapper
2026-02-06 增加参考图片
2026-02-06 增加一个脖子动画
2026-02-06 更新readme和一些材料参考图
2026-02-07 添加默认配置文件
2026-02-07 更新配置文件
2026-02-07 更新查找config文件逻辑
2026-02-08 更新readme
